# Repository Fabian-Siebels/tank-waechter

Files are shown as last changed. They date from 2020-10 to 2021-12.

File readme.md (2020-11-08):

# tank-waechter
#### by Fabian Siebels | 10.2020

### Anforderungen

Überwachung folgender Funktionen:
- Überwachung der Milchtemperatur mit Alarmierung für den Michlerzeuger
- Überwachung des Rührwerks mit Alarmierung für den Milcherzeuger
- Überwachung der Mindest-Reinigungstemperatur
- Speicherung von Fehlermeldungen für mind. 30 Tage
- "Nicht laden"-Funktion

Sobald die Milch die in der Milchlieferung beschriebenden Qualitätsanforderungen nicht mehr erfüllt, muss der Tankwächter ein eindeutig wahrnehmbares optisches oder akustisches Signal abgeben ("Nicht laden" Funktion).

Die "Nicht laden" Funktion ist wie folgt definiert:
- Milchtemperatur mehr als 600 Minuten über 13 °C
- Milchtemperatur mehr als 360 Minuten über 16 °C
- Milchtemperatur mehr als 300 Minuten über 28 °C
- Netzwerkstörung mehr als 300 Minuten

## Installation

1.  1Wire aktivieren

```
sudo modprobe wire
sudo modprobe w1-gpio
sudo modprobe w1-therm
```

2. Für immer aktivieren
```
sudo nano /boot/config.txt

# 1-Wire Temperatursensor, Daten an Pin 4
dtoverlay=w1-gpio
gpiopin=4
```

#### Display

i2C aktivieren
sudo apt-get install python-smbus
sudo apt-get install i2c-tool
i2cdetect -y 1      <--- x27

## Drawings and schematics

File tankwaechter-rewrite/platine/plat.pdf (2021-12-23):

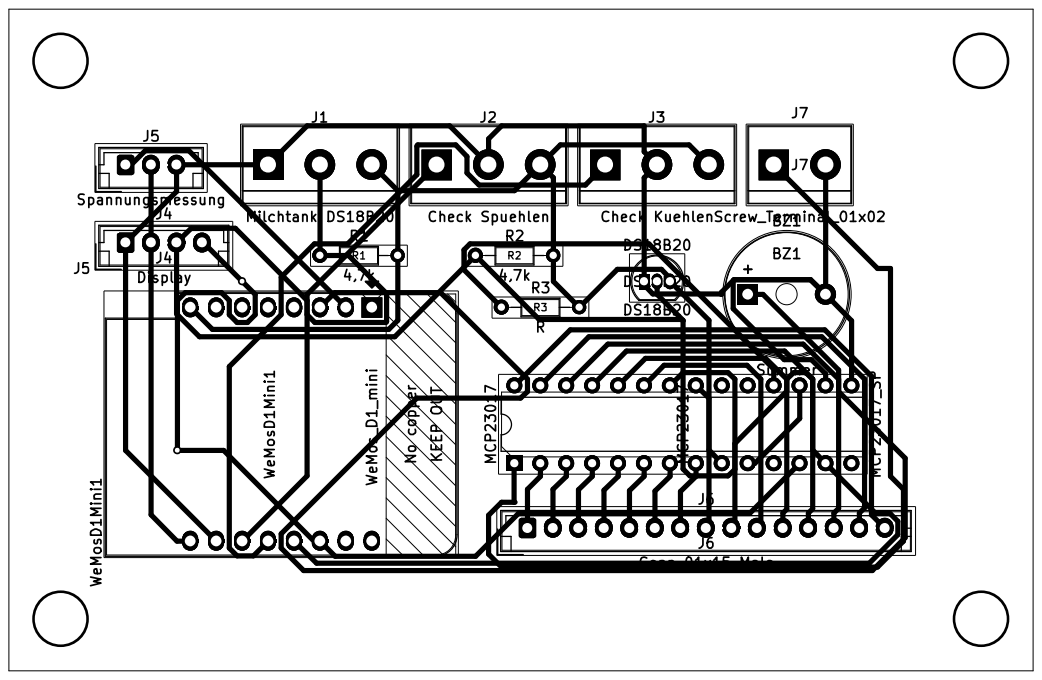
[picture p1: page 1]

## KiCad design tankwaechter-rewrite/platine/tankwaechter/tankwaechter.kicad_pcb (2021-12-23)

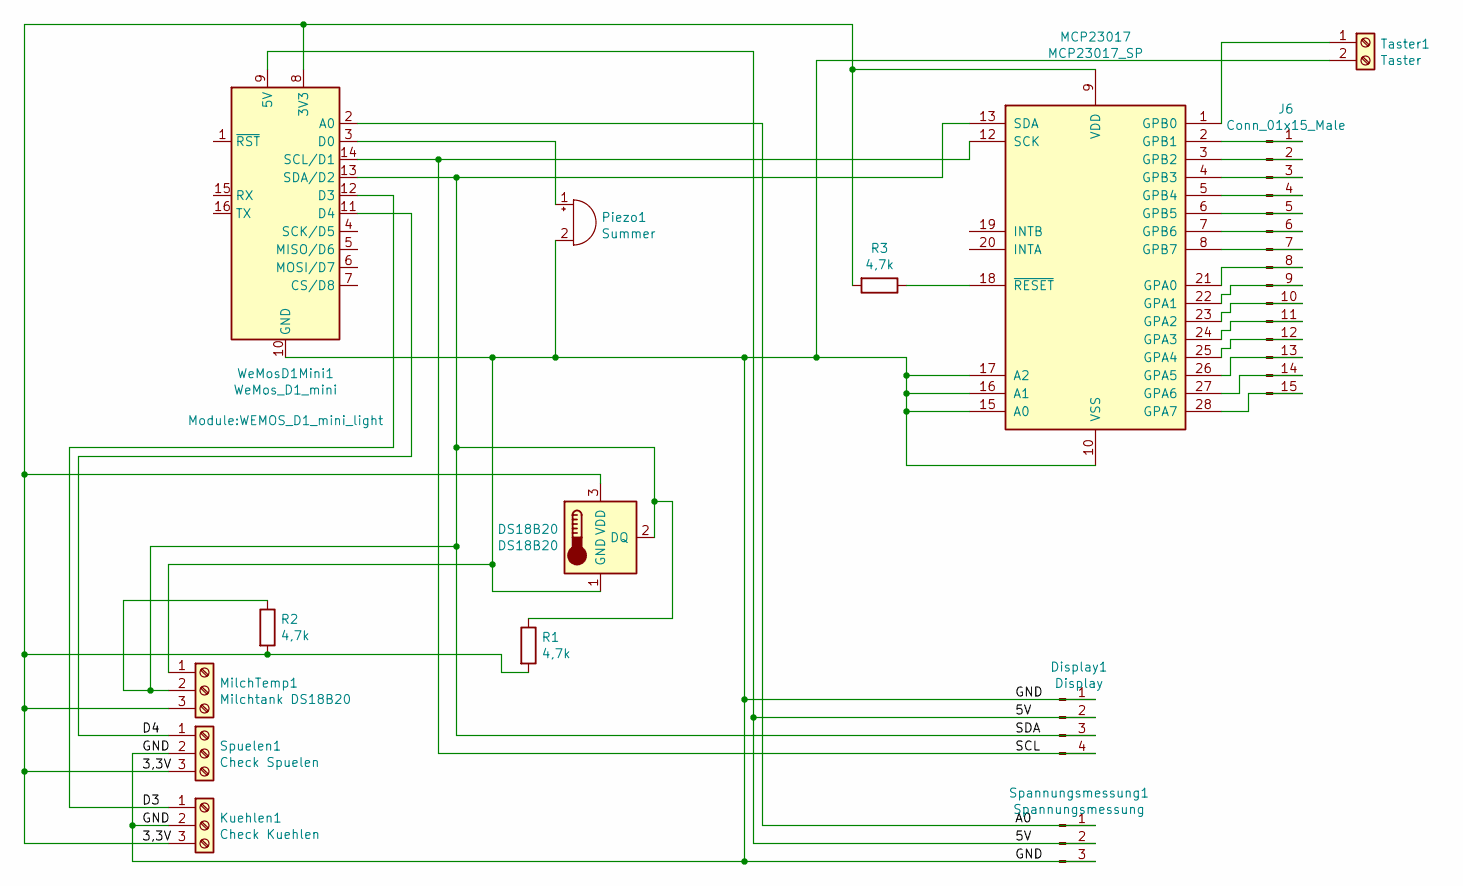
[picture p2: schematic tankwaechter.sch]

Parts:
DS18B20: DS18B20; TO-92_Inline
Display1: Display; JST_EH_B4B-EH-A_1x04_P2.50mm_Vertical
J6: Conn_01x15_Male; JST_EH_B15B-EH-A_1x15_P2.50mm_Vertical
Kuehlen1: Check Kuehlen; TerminalBlock_bornier-3_P5.08mm
MCP23017: MCP23017_SP; DIP-28_W7.62mm
MilchTemp1: Milchtank DS18B20; TerminalBlock_bornier-3_P5.08mm
Piezo1: Summer; Buzzer_12x9.5RM7.6
R1, R2, R3: 4,7k; R_Axial_DIN0204_L3.6mm_D1.6mm_P7.62mm_Horizontal
Spannungsmessung1: Spannungsmessung; JST_EH_B3B-EH-A_1x03_P2.50mm_Vertical
Spuelen1: Check Spuelen; TerminalBlock_bornier-3_P5.08mm
Taster1: Taster; TerminalBlock_bornier-2_P5.08mm
WeMosD1Mini1: WeMos_D1_mini; WEMOS_D1_mini_light

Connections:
/3,3V: DS18B20.3 (VDD), Kuehlen1.3, MCP23017.9 (VDD), MilchTemp1.3, R1.2, R2.2, R3.2, Spuelen1.3, WeMosD1Mini1.8 (3V3)
/5V: Display1.2, Spannungsmessung1.2, WeMosD1Mini1.9 (5V)
/A0: Spannungsmessung1.1, WeMosD1Mini1.2 (A0)
/D3: Kuehlen1.1, WeMosD1Mini1.12 (D3)
/D4: Spuelen1.1, WeMosD1Mini1.11 (D4)
/GND: DS18B20.1 (GND), Display1.1, Kuehlen1.2, MCP23017.10 (VSS), MCP23017.15 (A0), MCP23017.16 (A1), MCP23017.17 (A2), MilchTemp1.1, Piezo1.2 (+), Spannungsmessung1.3, Spuelen1.2, Taster1.2, WeMosD1Mini1.10 (GND)
/SCL: Display1.4, MCP23017.12 (SCK), WeMosD1Mini1.14 (SCL/D1)
/SDA: DS18B20.2 (DQ), Display1.3, MCP23017.13 (SDA), MilchTemp1.2, R1.1, R2.1, WeMosD1Mini1.13 (SDA/D2)
unnamed: J6.1, MCP23017.2 (GPB1)
unnamed: J6.2, MCP23017.3 (GPB2)
unnamed: J6.3, MCP23017.4 (GPB3)
unnamed: J6.4, MCP23017.5 (GPB4)
unnamed: J6.5, MCP23017.6 (GPB5)
unnamed: J6.6, MCP23017.7 (GPB6)
unnamed: J6.7, MCP23017.8 (GPB7)
unnamed: J6.8, MCP23017.21 (GPA0)
unnamed: J6.9, MCP23017.22 (GPA1)
unnamed: J6.10, MCP23017.23 (GPA2)
unnamed: J6.11, MCP23017.24 (GPA3)
unnamed: J6.12, MCP23017.25 (GPA4)
unnamed: J6.13, MCP23017.26 (GPA5)
unnamed: J6.14, MCP23017.27 (GPA6)
unnamed: J6.15, MCP23017.28 (GPA7)
unnamed: MCP23017.1 (GPB0), Taster1.1
unnamed: MCP23017.18 (~RESET~), R3.1
unnamed: Piezo1.1 (-), WeMosD1Mini1.3 (D0)

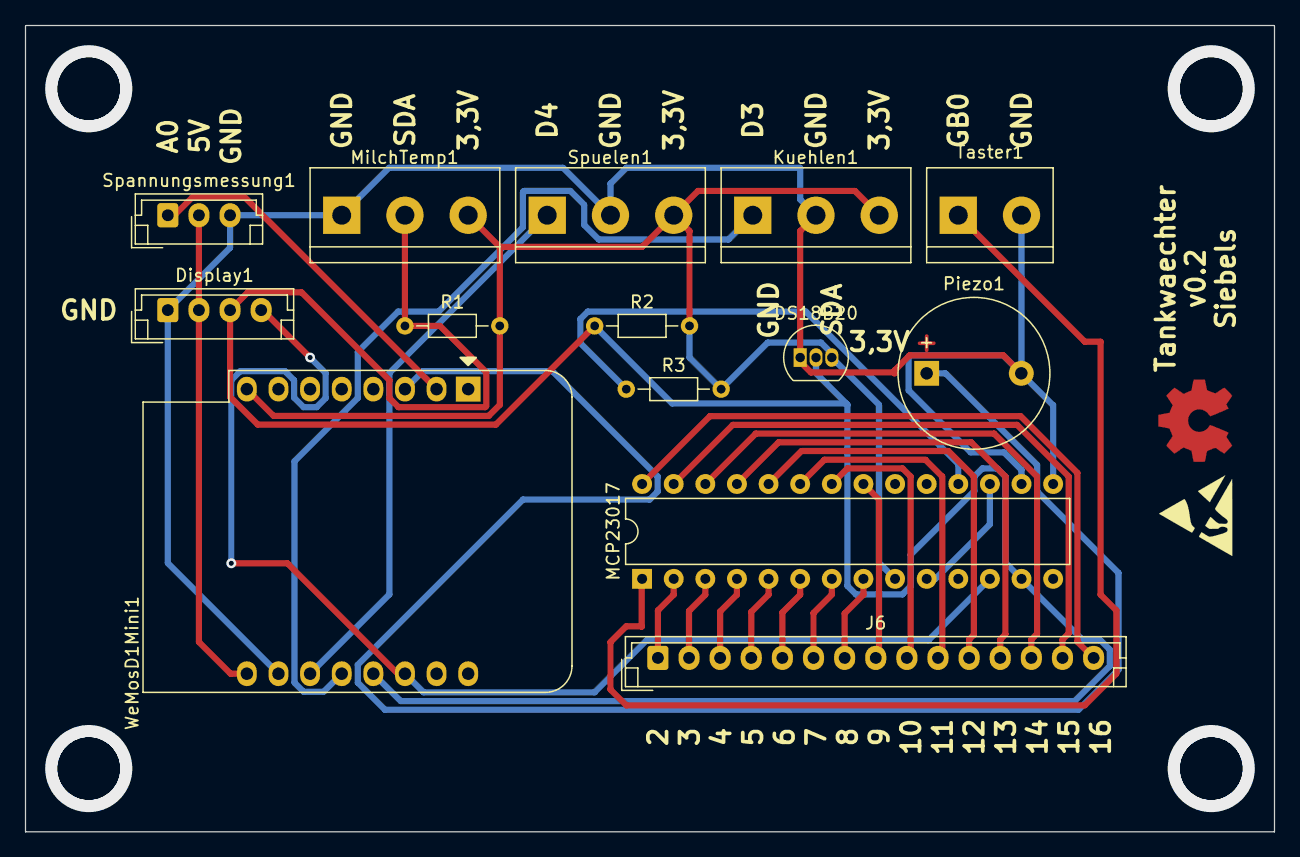
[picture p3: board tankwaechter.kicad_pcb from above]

Board: 2 copper layers, 100.3 x 64.8 mm, 14 parts (0 on the bottom side), 26 nets.

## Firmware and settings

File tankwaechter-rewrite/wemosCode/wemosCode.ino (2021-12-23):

#include <OneWire.h>
#include <DallasTemperature.h>
#include <LiquidCrystal_I2C.h>
#include <SD.h>
#include <NTPClient.h>
#include <ESP8266WiFi.h>
#include <WiFiClientSecure.h>
#include <WiFiUdp.h>
#include <UniversalTelegramBot.h>
#include <ArduinoJson.h>
#include <Adafruit_MCP23017.h>


const char *ssid     = "Fritz";
const char *password = "";

#define BOT_TOKEN ""

#define tid ""

X509List cert(TELEGRAM_CERTIFICATE_ROOT);
WiFiClientSecure secured_client;
UniversalTelegramBot bot(BOT_TOKEN, secured_client);

int Bot_mtbs = 1000; //mean time between scan messages
long Bot_lasttime;   //last time messages' scan has been done

WiFiUDP ntpUDP;
NTPClient timeClient(ntpUDP, "pool.ntp.org");

// MCP Portexpander intealisieren
Adafruit_MCP23017 mcp;

// SD Karte
const int chipSelect = D8;
File myFile;

// Der PIN D2 (GPIO 4) wird als BUS-Pin verwendet
#define ONE_WIRE_BUS 4

LiquidCrystal_I2C lcd(0x27,16,2);

OneWire oneWire(ONE_WIRE_BUS);
DallasTemperature DS18B20(&oneWire);
int sensorAnzahl = 0;

// Quittieren per Taster
int quittTasterState = 0;

// Summerpin Alarmsummer
int summer = 16;
unsigned long timerAlarm;

// In dieser Variable wird die Temperatur gespeichert
String temperatur;
float raumTemperatur;

// 0 = 600min ueber 13 Grad
// 1 = 360min ueber 16 Grad
// 2 = 300min ueber 28 Grad
// 3 = Ist ueber 600 min 13 Grad
// 4 = Ist ueber 360 min 26 Grad
// 5 = Ist ueber 300 min 28 Grad 
// 6 = 300 min Netzwerk weg
// 7 = Ist ueber 300 min Netzwerk weg
// 8 = Ist ausgeloest
unsigned long zeitSpeicher[] = {0,0,0,0,0,0,0,0,0};
//Timer fuer Delay leseTemp()
unsigned long timer = 0;
//Timer fuer Delay leseSpuehlen und leseKuehlen
unsigned long timerSpuelenKuehlen = 0;
unsigned long warteButton = 0;
int fehlerAnzeige = 0;

int statusSpuelen = 0;
int statusKuehlen = 0;

void setup(){
  Serial.begin(9600);
  mcp.begin();

  pinMode(summer, OUTPUT);
  // QuittTaster auf MCP
  mcp.pinMode(1, INPUT);

  WiFi.begin(ssid, password);
  secured_client.setTrustAnchors(&cert);

  while (WiFi.status() != WL_CONNECTED) {
    delay(1000);
    Serial.println("Ich verbinde mich mit dem Internet...");
  }
  
  Serial.println("Ich bin mit dem Internet verbunden!");

  timeClient.begin();

  bot.sendMessage(tid, "Tankwächter ist hochgefahren");
    
  // DS18B20 initialisieren
  //DS18B20.begin();
  DS18B20.begin();
  sensorAnzahl = DS18B20.getDeviceCount();
  Serial.println(sensorAnzahl, DEC);
  // LCD-Display initialisieren
  lcd.init();
  lcd.backlight();
  lcd.setCursor(0,0);
  lcd.print("    Starte...");
  lcd.setCursor(0,1);
  lcd.print("  Tankwaechter");
  delay(1000);
  leseTemp();
}

void handleNewMessages(int numNewMessages) {
  for(int i=0; i<numNewMessages; i++) {
    String chat_id = String(bot.messages[i].chat_id);
    String text = bot.messages[i].text;
    if (text == "/status") {
      bot.sendMessage(chat_id, "Temperatur: " + String(temperatur) + " °C", "");
    }
    if (text == "/quitt") {
      bot.sendMessage(chat_id, "System wird Quittiert!", "");
      if (fehlerAnzeige != 0) {
      fehlerAnzeige = 0;
      digitalWrite(summer, LOW);
      lcd.setCursor(0,1);
      lcd.print("   Quittiert!  ");
  } 
    }
    if (text == "/start") {
      String from_name = bot.messages[i].from_name;
      if (from_name == "") from_name = "Anonymous";

      String welcome = "Moin, " + from_name + "! \xF0\x9F\x90\xAE\n\n";
      welcome = welcome + "Mit folgenden Komandos kannst du mich fernsteuern: \xF0\x9F\x8E\xAE\n"; 
      welcome = welcome + "/status : Prüfe die Temperatur \xF0\x9F\x8C\xA1\n"; 
      welcome = welcome + "/quitt : Setze die Übertemperatur zurück \xE2\x9C\x94\n";
      bot.sendMessage(chat_id, welcome, "Markdown");
    }
  }
}


void leseTemp() {
  DS18B20.requestTemperatures();
  raumTemperatur = DS18B20.getTempCByIndex(0);
  temperatur = DS18B20.getTempCByIndex(1); 
  checkTemp();
  lcd.setCursor(1,0);
  lcd.print("Temp: " + temperatur + " \337C"); 
  switch (fehlerAnzeige){
    case 0:
      lcd.setCursor(0,1);
      if (statusSpuelen == 1){
        lcd.print("S Abholbereit!");
      } else if (statusKuehlen == 1){
        lcd.print("K Abholbereit!");
      }
      lcd.print("  Abholbereit!");
      break;
    case 1:
      lcd.setCursor(0,1);
      lcd.print(" Nicht Laden!!!");
      alarmSummer();
      break;
  }
  if (!SD.begin(chipSelect)) {
    Serial.println("Kann SD Karte nicht finden!");
    // TODO Fehlermeldung auf Display
    bot.sendMessage(tid, "Fehler: Kann die SD Karte nicht finden!", "");
    return;
  }

  //Alarm Summer alle 3 Sek an
  void alarmSummer() {
    if (fehlerAnzeige = 1) {
      if (millis() >= (3*1000) + timerAlarm){
      timerAlarm = millis();
      digitalWrite(summer, !digitalRead(summer));
      }
    }
  }

  // open the file. note that only one file can be open at a time,
  // so you have to close this one before opening another.
  myFile = SD.open("data.txt", FILE_WRITE);
  timeClient.update();
  
  // if the file opened okay, write to it:
  if (myFile) {
    String jsonString = "{\"zeit\":";
    jsonString += timeClient.getEpochTime();
    jsonString += ",\"temperatur\":";
    jsonString += temperatur;
    jsonString += ",\"raumTemperatur\":";
    jsonString += raumTemperatur;
    jsonString += ",\"spuehlen\":";
    jsonString += statusSpuelen;
    jsonString += ",\"kuehlen\":";
    jsonString += statusKuehlen;
    jsonString += ",\"alarm\":";
    jsonString += fehlerAnzeige;
    jsonString += "}";
    Serial.println(jsonString);
    myFile.println(jsonString);
    // close the file:
    myFile.close();
  } else {
    // if the file didn't open, print an error:
    Serial.println("Error, kann Datei nicht laden!");
    bot.sendMessage(tid, "Fehler: Kann die Log-Datei nicht laden", "");
  }
}

// Check Temperatur nach Zeit
void checkTemp() {
  if (statusSpuelen == 0 || statusKuehlen == 0 || statusKuehlen == 1){
    if (temperatur >= "28"){
    if (zeitSpeicher[2] >= 0 && zeitSpeicher[5] == 0) {
      zeitSpeicher[2] = millis(); 
      zeitSpeicher[3] = 0;
      zeitSpeicher[4] = 0;
      zeitSpeicher[5] = 1;
    }
    if (millis() >= zeitSpeicher[2] + (300*60000)){
      zeitSpeicher[5] = 0;
      fehlerAnzeige = 1;
      String warnung = "Die Temperatur der Milch ist seit 300 Minuten über 28 °C!\n\n";
      warnung += "Möchtest du die Warnung Quittieren?\n -> /quitt <- ";
      bot.sendMessage(tid, warnung, "Markdown");
    }
  }
  else if (temperatur >= "16"){
    if (zeitSpeicher[1] >= 0 && zeitSpeicher[4] == 0) {
      zeitSpeicher[1] = millis(); 
      zeitSpeicher[3] = 0;
      zeitSpeicher[4] = 1;
      zeitSpeicher[5] = 0;
    }
    if (millis() >= zeitSpeicher[1] + (2*60000)){
      zeitSpeicher[4] = 0;
      fehlerAnzeige = 1;
      String warnung = "Die Temperatur der Milch ist seit 360 Minuten über 16 °C!\n\n";
      warnung += "Möchtest du die Warnung Quittieren?\n -> /quitt <- ";
      bot.sendMessage(tid, warnung, "Markdown"); 
    }
  }
  else if (temperatur >= "13") {
    if (zeitSpeicher[0] >= 0 && zeitSpeicher[3] == 0) {
      zeitSpeicher[0] = millis(); 
      zeitSpeicher[3] = 1;
      zeitSpeicher[4] = 0;
      zeitSpeicher[5] = 0;
    }
    if (millis() >= zeitSpeicher[0] + (1*60000)){
      zeitSpeicher[3] = 0; 
      fehlerAnzeige = 1;
      
      String warnung = "Die Temperatur der Milch ist seit 600 Minuten über 13 °C!\n\n";
      warnung += "Möchtest du die Warnung Quittieren?\n -> /quitt <- ";
      bot.sendMessage(tid, warnung, "Markdown");
    }
  }
  }
}

void loop(){  
  if (millis() >= (30*1000) + timer){
    timer = millis();
    leseTemp();
  }

  if (millis() >= (5*1000) + timerSpuelenKuehlen) {
    timerSpuelenKuehlen = millis();
    int leseStatusSpuelen = digitalRead(0);
    if (leseStatusSpuelen == LOW) {
      Serial.println("Spuelen aktiv");
      statusSpuelen = 1;
    } else {
      statusSpuelen = 0;
    }
    int leseStatusKuehlen = digitalRead(2);
    if (leseStatusKuehlen == LOW) {
      Serial.println("Kuehlen aktiv");
      statusKuehlen = 1;
    } else {
      statusKuehlen = 0;
    }
  }
  
  if (millis() > Bot_lasttime + Bot_mtbs)  {
    int numNewMessages = bot.getUpdates(bot.last_message_received + 1);
    while(numNewMessages) {
      handleNewMessages(numNewMessages);
      numNewMessages = bot.getUpdates(bot.last_message_received + 1);
    }
    Bot_lasttime = millis();
  }

// Hardware Quittiertaster abfragen
  if (mcp.digitalRead(quittTaster)==HIGH) {
    switch(quittTasterState){
      case 0;
        // Hochzaehlen
        quittTasterState = 1;
        break;
      case 1;
        // Meldung erhalten
        quittTasterState = 2;
        break;
      case 2;
        // Meldung entfernen
        quittTasterState = 0;
        fehlerAnzeige = 0;
        digitalWrite(summer, LOW);
    }
  }
}

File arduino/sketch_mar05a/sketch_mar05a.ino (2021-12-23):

#include <OneWire.h>
#include <DallasTemperature.h>
#include <LiquidCrystal_I2C.h>

// Der PIN D2 (GPIO 4) wird als BUS-Pin verwendet
#define ONE_WIRE_BUS 4

int incomingByte = 0; // Für eingehende serielle Daten

LiquidCrystal_I2C lcd(0x27,16,2);

OneWire oneWire(ONE_WIRE_BUS);
DallasTemperature DS18B20(&oneWire);

// In dieser Variable wird die Temperatur gespeichert
float temperatur;

// 0 = 600min ueber 13 Grad
// 1 = 360min ueber 16 Grad
// 2 = 300min ueber 28 Grad
// 3 = Ist ueber 600 min 13 Grad
// 4 = Ist ueber 360 min 26 Grad
// 5 = Ist ueber 300 min 28 Grad 
// 6 = 300 min Netzwerk weg
// 7 = Ist ueber 300 min Netzwerk weg
// 8 = Ist ausgeloest
unsigned long zeitSpeicher[] = {0,0,0,0,0,0,0,0,0};
unsigned long timer = 0;
unsigned long warteButton = 0;
int fehlerAnzeige = 0;

int quittButtonZaehler = 0;
int reiniugungsButtonZaehler = 0;
int motorButtonZaehler = 0;

void setup(){
  Serial.begin(115200);

  // QuitButton
  pinMode(A0, INPUT);
  // DS18B20 initialisieren
  DS18B20.begin();
  // LCD-Display initialisieren
  lcd.init();
  lcd.backlight();
  lcd.setCursor(0,0);
  lcd.print("    Starte...");
  lcd.setCursor(0,1);
  lcd.print("  Tankwaechter");
}



void leseTemp() {
  DS18B20.requestTemperatures();
  temperatur = DS18B20.getTempCByIndex(0);
  checkTemp();
  // Ausgabe im seriellen Monitor
  Serial.println(String(temperatur) + " °C");
  lcd.setCursor(1,0);
  lcd.print("Temp: " + String(temperatur) + " \337C"); 
  switch (fehlerAnzeige){
    case 0:
      lcd.setCursor(0,1);
      lcd.print("  Abholbereit!");
      break;
    case 1:
      lcd.setCursor(0,1);
      lcd.print(" Nicht Laden!!!");
      break;
  }
}

// Check Temperatur nach Zeit
void checkTemp() {
  if (temperatur >= 28){
    Serial.println("Ueber 28 Grad");
    if (zeitSpeicher[2] >= 0 && zeitSpeicher[5] == 0) {
      zeitSpeicher[2] = millis(); 
      zeitSpeicher[3] = 0;
      zeitSpeicher[4] = 0;
      zeitSpeicher[5] = 1;
    }
    if (millis() >= zeitSpeicher[2] + (300*60000)){
      Serial.println("Ausgeloest! Temperatur ueber 28 Grad fuer 300 Minuten!");
      zeitSpeicher[5] = 0;
      fehlerAnzeige = 1;
    }
  }
  else if (temperatur >= 16){
    Serial.println("Ueber 16 Grad");
    if (zeitSpeicher[1] >= 0 && zeitSpeicher[4] == 0) {
      zeitSpeicher[1] = millis(); 
      zeitSpeicher[3] = 0;
      zeitSpeicher[4] = 1;
      zeitSpeicher[5] = 0;
    }
    if (millis() >= zeitSpeicher[1] + (1*60000)){
      Serial.println("Ausgeloest! Temperatur ueber 16 Grad fuer 360 Minuten!");
      zeitSpeicher[4] = 0;
      fehlerAnzeige = 1; 
    }
  }
  else if (temperatur >= 13) {
    Serial.println("Ueber 13 Grad");
    if (zeitSpeicher[0] >= 0 && zeitSpeicher[3] == 0) {
      zeitSpeicher[0] = millis(); 
      zeitSpeicher[3] = 1;
      zeitSpeicher[4] = 0;
      zeitSpeicher[5] = 0;
    }
    if (millis() >= zeitSpeicher[0] + (1*60000)){
      Serial.println("Ausgeloest! Temperatur ueber 13 Grad fuer 600 Minuten!");
      zeitSpeicher[3] = 0; 
      fehlerAnzeige = 1;
    }
  }
}

void quittieren() {
  if (quittButtonZaehler >= 1 && fehlerAnzeige != 0) {
    lcd.setCursor(0,1);
    lcd.print("   Quittiert!  ");
    Serial.println("Quittiert: Summer");
  } 
  else if (quittButtonZaehler >= 5 && fehlerAnzeige != 0) {
    fehlerAnzeige = 0;
    lcd.setCursor(0,1);
    lcd.print("   Quittiert!  ");
    Serial.println("Quittiert: Fehler");
  }
}



void loop(){

  if (Serial.available() > 0) {
    // Lies das eingehende Byte:
    incomingByte = Serial.read();

    // Ausgeben:
    Serial.print("I received: ");
    Serial.println(incomingByte, DEC);

    switch (incomingByte) {
    case 10:
      if (fehlerAnzeige != 0) {
        lcd.setCursor(0,1);
        lcd.print("   Quittiert!  ");
        Serial.println("Quittiert: Summer");
      }
      break;
    case 11:
      if (fehlerAnzeige =! 0) {
        fehlerAnzeige = 0;
        lcd.setCursor(0,1);
        lcd.print("   Quittiert!  ");
        Serial.println("Quittiert: Fehler");
      }
      break;
  }
  }
  
  if (millis() >= (30*1000) + timer){
    timer = millis();
    leseTemp();
  }

}

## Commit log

2020-10-24 influx +
    [tankwaechter.kicad_pcb, tankwaechter.sch]
2020-10-24 sensorparser und query
2020-10-27 login per pin mit dublikatsprüfung
2020-10-30 webserver und api hinzugefügt
2021-03-05 arduino funkt version
